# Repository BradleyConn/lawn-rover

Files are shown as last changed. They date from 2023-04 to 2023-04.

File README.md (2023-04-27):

# lawn-rover-program

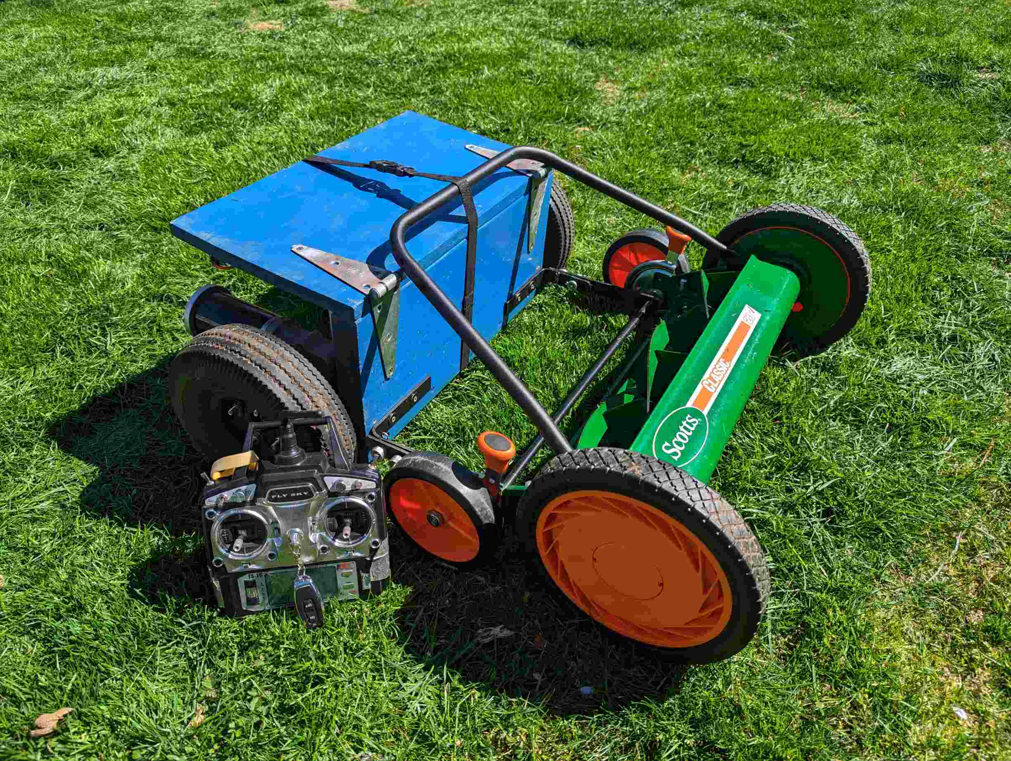
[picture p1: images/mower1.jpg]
Mower


Part of the lawn rover project. See [www.bradleyconn.space](https://www.bradleyconn.space/) for more details.
This is the main controller to interface with the remote reciever, interpret the signals, and interface to the motor drivers to drive the wheels.

An esp32 was used as I already had one readily available. Most microcontrollers would work. The Arduino IDE was used for its ease of use and effectiveness.

Everything was kept in a single file for simplicity, however that file has grown quite large and separate files should probably be considered.

## ESP32 wiring diagram
Below is how the ESP32 was connected to the R6B Receiver and connectors that attached to the wheel motor driver boards.

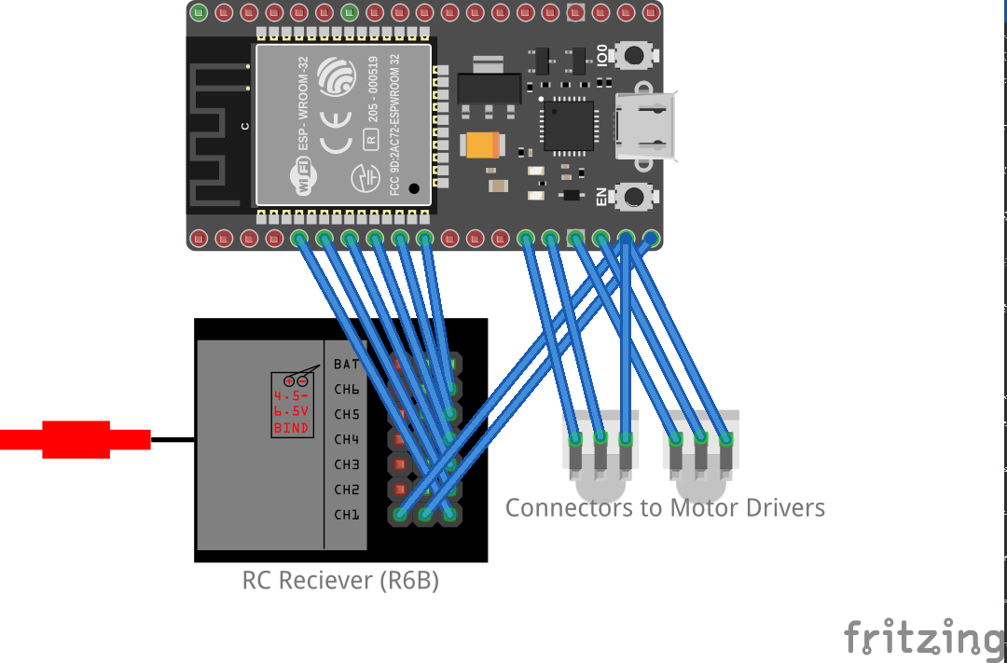
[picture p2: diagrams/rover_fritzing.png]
Wiring Diagram


## System block diagram

A block diagram of the entire system can be seen below. The microcontroller which this repo is concerned with is shown at the bottom.

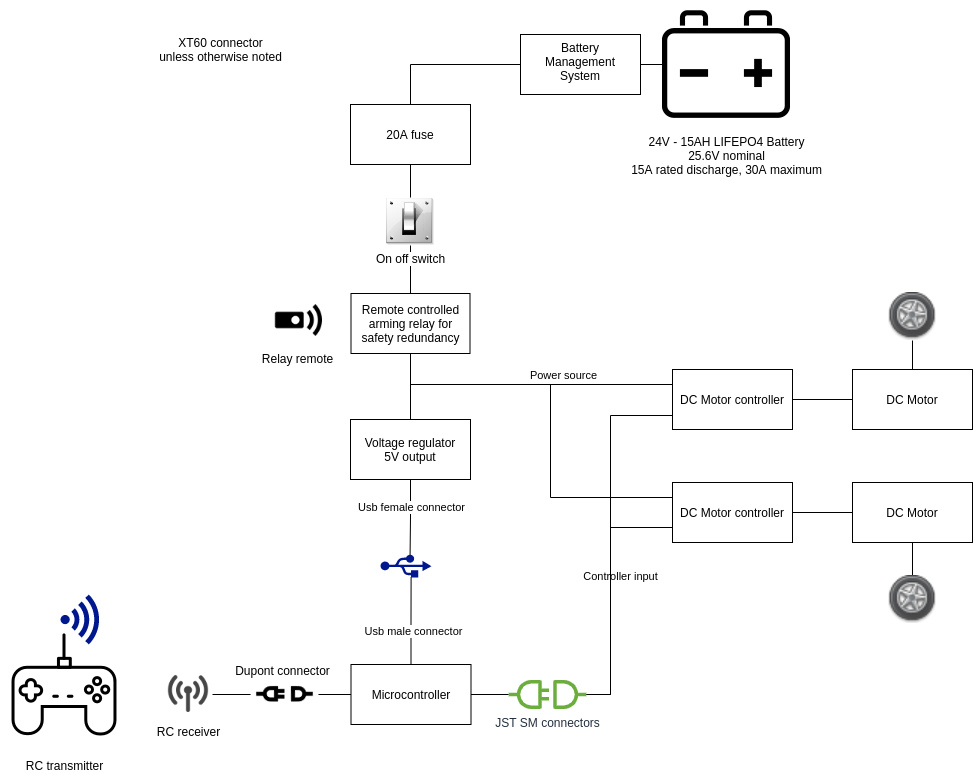
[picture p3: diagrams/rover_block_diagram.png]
System Block Diagram


And the actual wiring inside the system can be seen below.

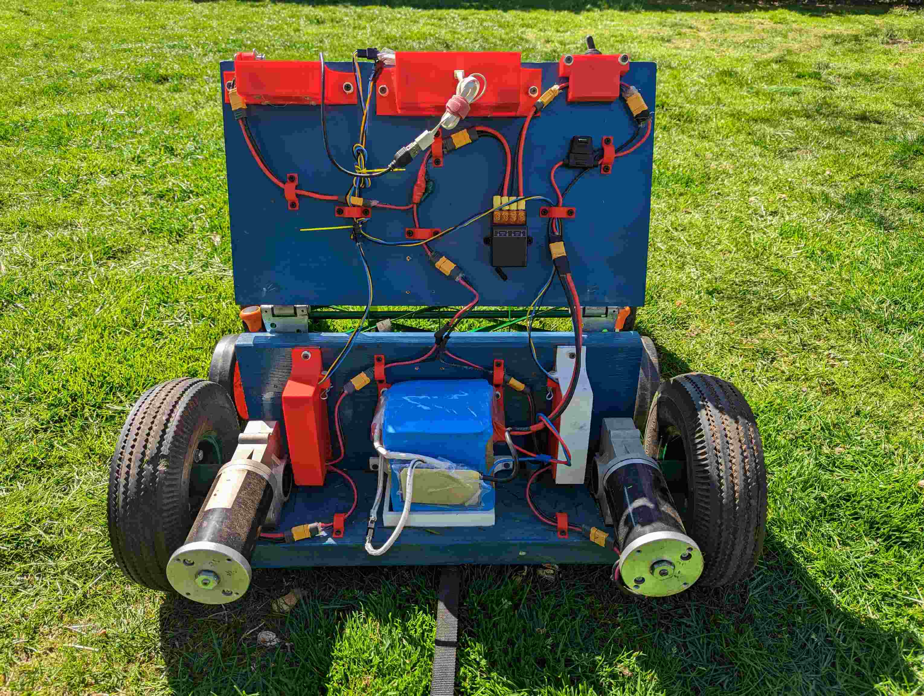
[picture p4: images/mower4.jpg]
Mower Inside


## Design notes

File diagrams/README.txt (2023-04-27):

rover_fritzing.png - A quick little wire diagram of how the esp32 connects to the RC reciever (R6B) and the two motor drivers.

rover_block_diagram.png - A block diagriam of the entire system. The microcontroller (and thus this repo) is labeled microcontroller. This is the brains behind the entire project, and you can see where it fits in with the overall project.

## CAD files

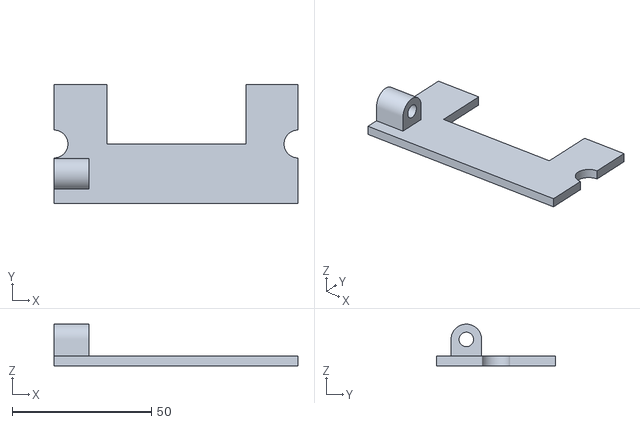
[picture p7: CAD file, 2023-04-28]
cad/stl/converter_lid_v1.stl
87.6 x 42.6 x 15.0

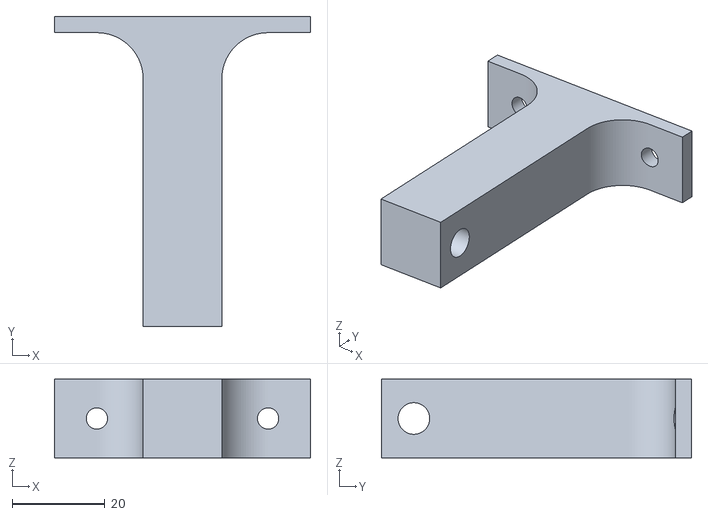
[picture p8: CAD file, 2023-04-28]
cad/stl/battery_arm.stl
55.4 x 67.0 x 17.0

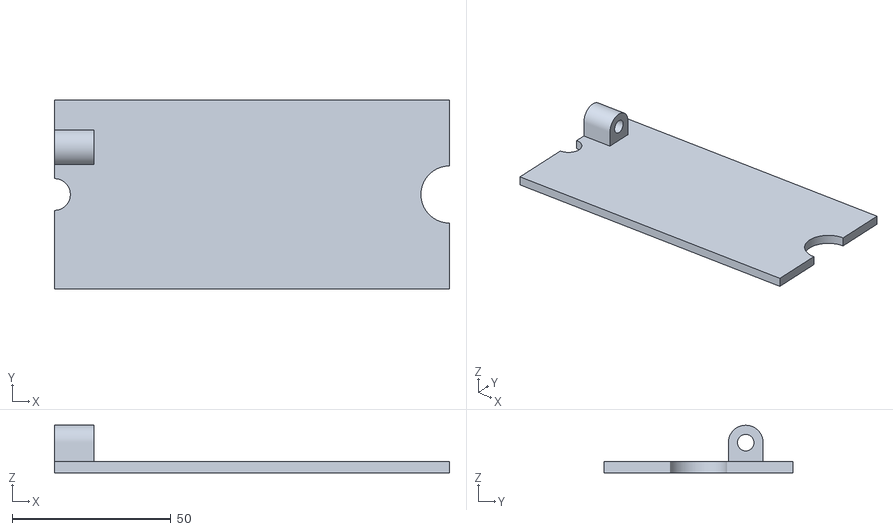
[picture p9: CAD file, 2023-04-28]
cad/stl/cytroncase_lid_v2_mirrored.stl
124.6 x 59.6 x 15.0

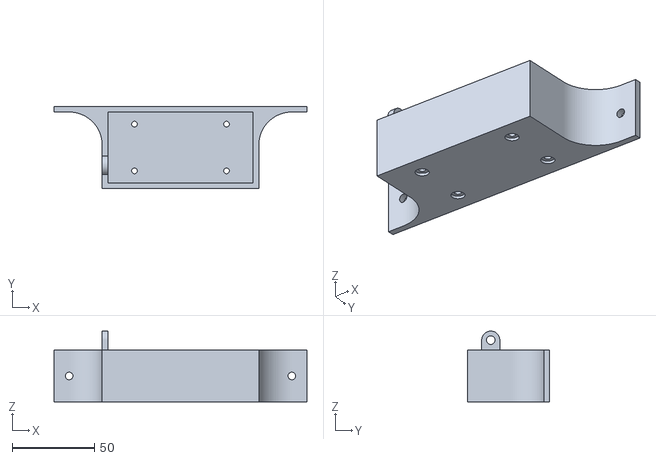
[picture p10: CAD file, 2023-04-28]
cad/stl/converter_v1.stl
153.4 x 50.0 x 43.0

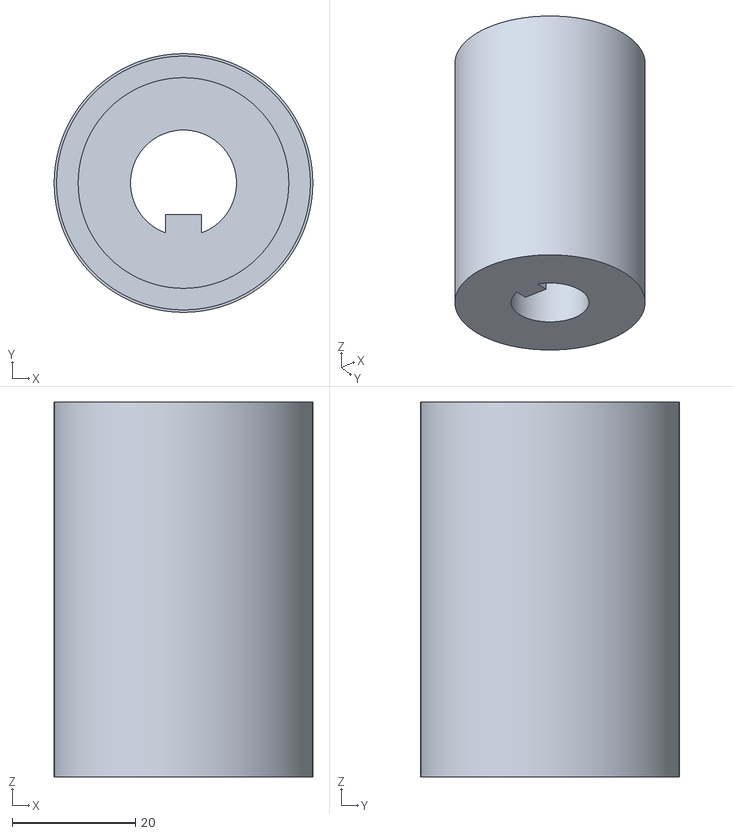
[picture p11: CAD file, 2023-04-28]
cad/stl/height_test.stl
42.0 x 42.0 x 60.9

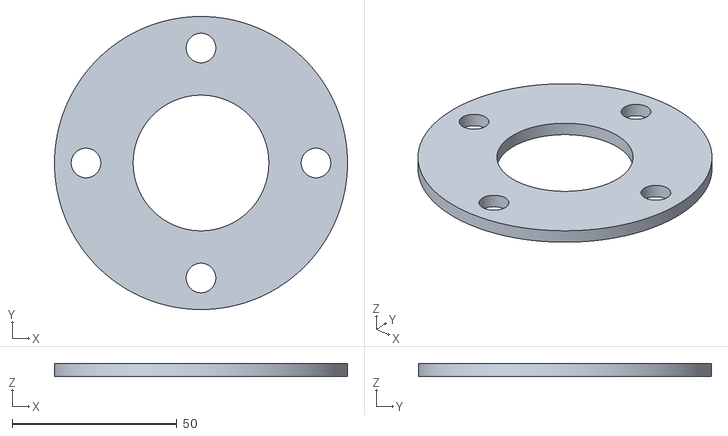
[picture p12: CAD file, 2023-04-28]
cad/stl/pipe_mount.stl
89.0 x 89.0 x 4.00

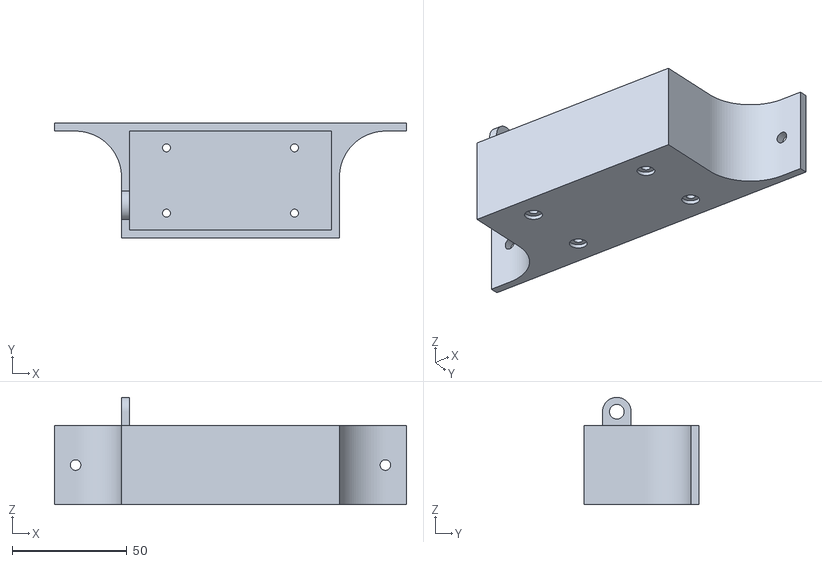
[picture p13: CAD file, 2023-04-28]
cad/stl/regulator_v2.stl
153.4 x 50.0 x 46.8

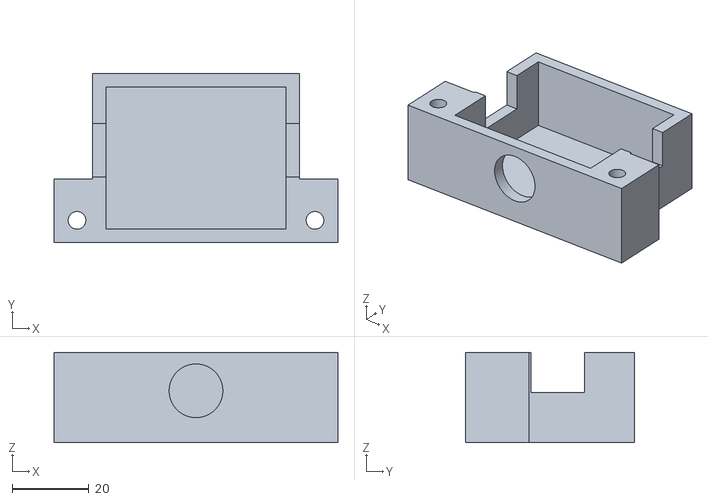
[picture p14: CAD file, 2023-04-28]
cad/stl/toggle_switch_v2.stl
74.0 x 44.0 x 23.5

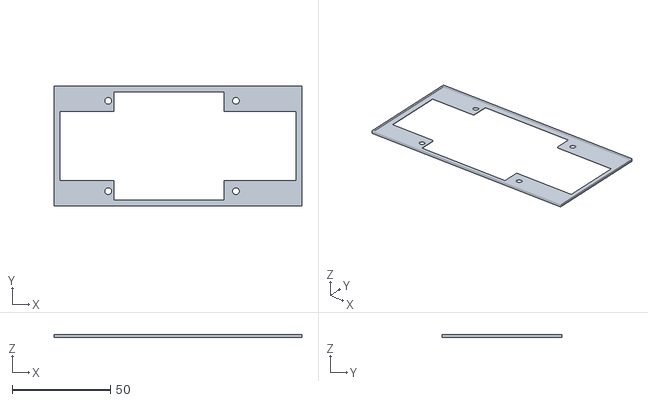
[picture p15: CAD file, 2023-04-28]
cad/stl/esp32-test.stl
126.2 x 61.2 x 1.60

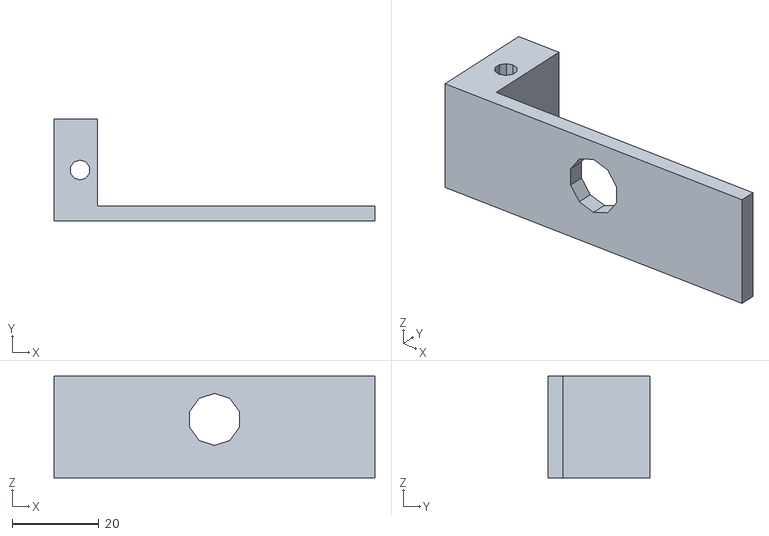
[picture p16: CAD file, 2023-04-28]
cad/stl/toggle_switch.stl
74.0 x 23.5 x 23.5

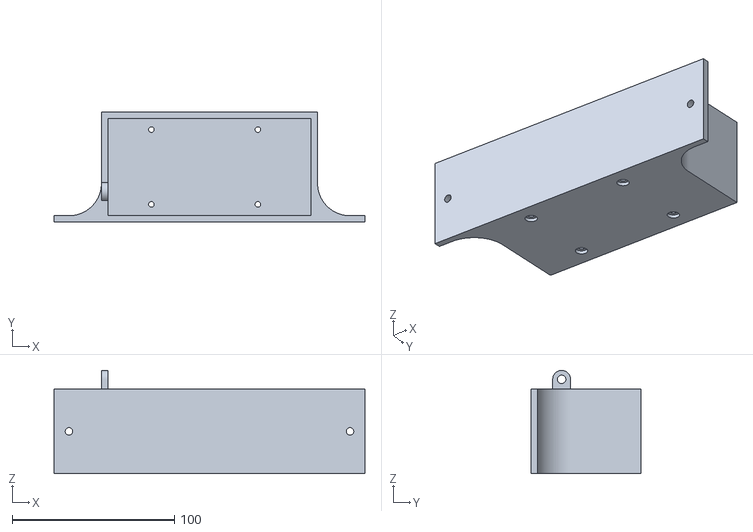
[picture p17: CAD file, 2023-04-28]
cad/stl/esp32.stl
191.4 x 68.0 x 63.5

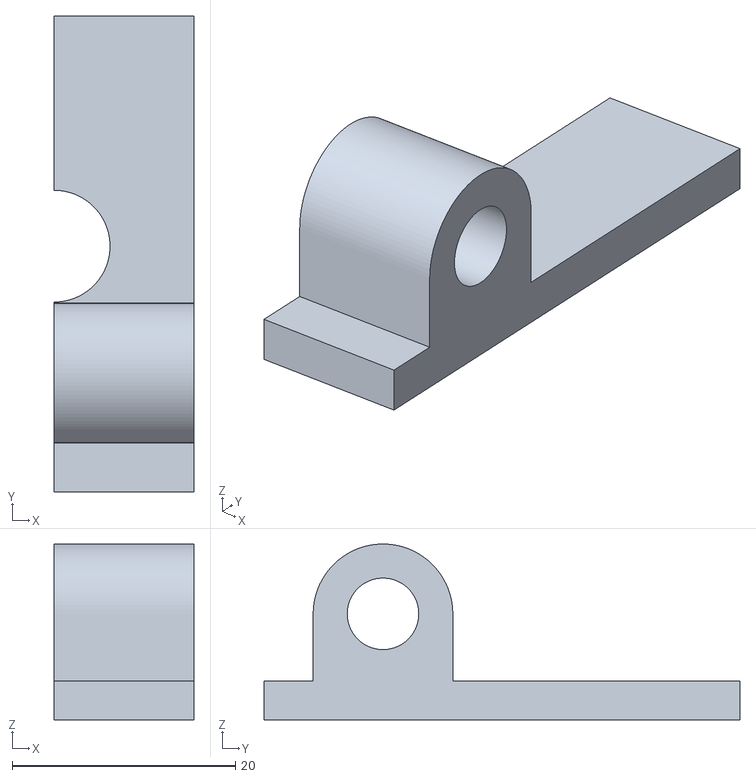
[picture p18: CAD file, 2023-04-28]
cad/stl/regulator_lid_v2.stl
12.5 x 42.6 x 15.8

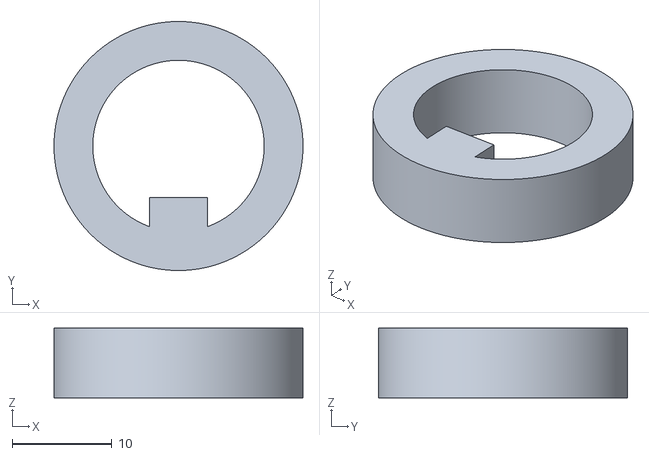
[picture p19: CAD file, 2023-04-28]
cad/stl/keyed_coupler.stl
25.0 x 25.0 x 7.00

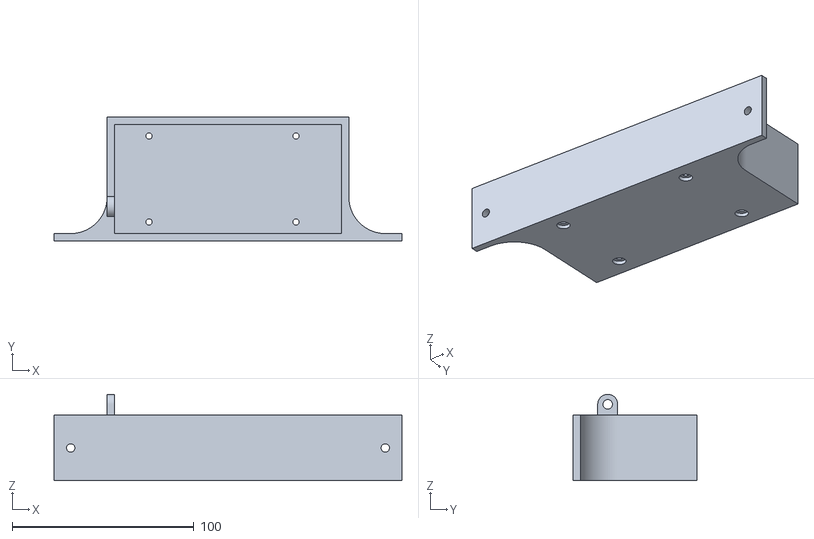
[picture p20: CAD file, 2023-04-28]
cad/stl/cytroncase_v2.stl
191.4 x 68.0 x 47.5

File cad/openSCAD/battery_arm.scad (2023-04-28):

length = 60;//52;
width = 10;//86;
height = 10;
wall = 3.5;
o_width = width + wall + wall;
o_length = length + wall + wall;
o_height = height + wall + wall;

resolution = 100;

$fn = resolution;

// outer box
standoff_id=3.45;
standoff_od=7;
standoff_od_wall_depth = wall-2;
standoff_width = 55.8;
standoff_length = 28.4;
// main box
//add the pin mechanism
pin_od = 11;
pin_id = 5.2*(4/3)-.1;
wall_offset = 6;
difference() {
    cube([o_width, o_length, o_height]);
    rotate([0,90,0]) {
        translate([-(height+wall+wall)/2,wall+wall,0]) {
            cylinder(h=9000, d=pin_id);   
        }
    }
}
//}


mount_arm_surface_area = 10;
screwhole_size = 4.6;
//box_mount_hole_1
translate([0,o_length,0]) {
mirror([0,1,0]) {
rotate(90){
    difference() {
        union() {
            difference() {
                cube([mount_arm_surface_area+wall, mount_arm_surface_area, o_height]);
                // angled for strength
                translate([mount_arm_surface_area+wall, mount_arm_surface_area, -1]){
                    cylinder(h=9999, r=mount_arm_surface_area);
                }
            }
            cube([wall, mount_arm_surface_area+screwhole_size*2, o_height]);
        }
        // screw hole
        rotate([0,90,0]) {
            translate([-o_height/2, mount_arm_surface_area, -1]){
                cylinder(h=9999, d=screwhole_size);
            }
        }
    }
}
//box mount hole 2
//copied and pasted but translated an mirrored
translate([o_width, 0, 0]){
    mirror([1,0,0]){
        rotate(90) {
            difference() {
                union() {
                    difference() {
                        cube([mount_arm_surface_area+wall, mount_arm_surface_area, o_height]);
                        // angled for strength
                        translate([mount_arm_surface_area+wall, mount_arm_surface_area, -1]){
                            cylinder(h=9999, r=mount_arm_surface_area);
                        }
                    }
                    cube([wall, mount_arm_surface_area+screwhole_size*2, o_height]);
                }
                // screw hole
                rotate([0,90,0]) {
                    translate([-o_height/2, mount_arm_surface_area, -1]){
                        cylinder(h=9999, d=screwhole_size);
                    }
                }
            }
        }
    }
}
}
}

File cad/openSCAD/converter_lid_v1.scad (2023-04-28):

length = 43-.4;//52;
width = 88-.4;//86;
height = 32;
wall = 3.5;
o_width = width + wall + wall;
o_length = length + wall + wall;
o_height = height + wall;

resolution = 100;

$fn = resolution;

// outer box
standoff_id=3.45;
standoff_od=7;
standoff_od_wall_depth = wall-2;
standoff_width = 80.8;
standoff_length = 47.25;
//difference(){
    // main box
    //cube([o_width, o_length, o_height]);
    translate([wall, wall, 0]) {
        translate([0, 0, wall]) {
            // 9999 to take out the whole face
            difference(){
            cube([width, length, wall]);
                translate([width, length/2, 0]) {
                    cylinder(h=100, r=5);
                }
                translate([0, length/2, 0]) {
                    cylinder(h=100, r=5);
                }
                        translate([19, length/2, 0]) {

            cube([50, length/2, wall]);
                        }

            }
        }
    }
//}


//add the pin mechanism
pin_od = 11;
pin_id = 5.2;
pin_len = 16;
wall_offset = 6;
translate([wall, (1/4)*length+wall-pin_od/2, wall+wall]){
    difference() {
        union(){
            cube([pin_len-wall, pin_od, wall_offset]);
            rotate([0,90,0]) {
                translate([-wall_offset,pin_od/2,0]) {
                    cylinder(h=pin_len-wall, d=pin_od);
                }
            }
        }
        rotate([0,90,0]) {
            translate([-wall_offset,pin_od/2,0]) {
                cylinder(h=pin_len-wall, d=pin_id);   
            }
        }
    }
}

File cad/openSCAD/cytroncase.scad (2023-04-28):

/**
 * pin_length is measured along the same axis as the length of the board.
 * pin_width is the width of the bottom of the pins, where they're widest.
 * pin_thickness is measured along the same axis as the board thickness.
 * tail_width is the width of the tails where they meet the bottom of the pins, where they're narrowest.
 */
module dovetail_pins(pin_length=.75, pin_width=1, pin_thickness=.75, pin_count=4, angle=15, tail_width=1) {
    intersection() {
        translate([0.005, 0.005, 0.005]) cube([(pin_count-1)*(pin_width+tail_width)-0.01, pin_length-0.01, pin_thickness-0.01]);
        dovetail_pins_idealized(
            pin_length=pin_length,
            pin_width=pin_width,
            pin_thickness=pin_thickness,
            pin_count=pin_count,
            angle=angle,
            tail_width=tail_width
        );
    }
}

/**
 * tail_length is measured along the same axis as the length of the board.
 * tail_width is the width of the tails where they meet the board, where they're narrowest.
 * tail_thickness is measured along the same axis as the board thickness.
 * pin_width is the width of the bottom of the pins, where they're widest.
 */
module dovetail_tails(tail_length=.75, tail_width=1, tail_thickness=.75, tail_count=3, angle=15, pin_width=1) {
    pin_count = tail_count + 1;
    pin_thickness = tail_length;
    pin_length = tail_thickness;
    
    translate([0, 0, tail_thickness]) {
        rotate([-90, 0, 0]) {
            translate([0, 0, -0.005]) {
                difference() {
                    translate([0.005, 0.005, 0.005]) {
                        cube([(pin_count-1)*(pin_width+tail_width)-0.01, tail_thickness-0.01, tail_length-0.01]);
                    }

                    dovetail_pins_idealized(
                        pin_length=pin_length,
                        pin_width=pin_width,
                        pin_thickness=pin_thickness,
                        pin_count=pin_count,
                        angle=angle,
                        tail_width=tail_width
                    );
                }
            }
        }
    }
}

/**
 * Used for generating both pins and tails. Don't call this directly.
 */
module dovetail_pins_idealized(
    pin_length=.75,
    pin_width=1,
    pin_thickness=.75,
    pin_count=4,
    angle=15,
    tail_width=1) {
        
    pin_width_top = pin_width - ( 2 * tan(angle) * pin_thickness );
    
    translate([0, pin_length, 0]) {
        rotate([90, 0, 0]) {
            intersection() {
                cube([(pin_count-1)*(pin_width+tail_width), pin_thickness, pin_length]);
                
                for (pin = [0:pin_count-1]) {
                    translate([pin * (pin_width + tail_width), 0]) {
                        linear_extrude(pin_length) {
                            polygon([
                                [-pin_width/2, 0], 
                                [-pin_width_top/2, pin_thickness],
                                [pin_width_top/2, pin_thickness],
                                [pin_width/2, 0]
                            ]);
                        }
                    }
                }
            }
        }
    }
}

/**
 * Determine the width the pins need to be once the tail widths are chosen.
 */
function pin_width (tail_width, tail_count, board_width) = ( board_width - (tail_width * tail_count) ) / (tail_count);

/**
 * Construct a board with tails cut into it. board_length includes the length of the tails.
 */
module board_with_dovetail_tails(board_length, board_width, board_thickness, tail_length, tail_width, pin_width, tail_count, angle) {
    
    tail_thickness = board_thickness;
    
    pin_width = pin_width(tail_width = tail_width, tail_count=tail_count, board_width=board_width);
    translate([0, board_length - ( 2 * tail_length) + tail_length, 0]) {
        dovetail_tails(tail_length=tail_length, tail_width=tail_width, tail_thickness=tail_thickness, tail_count=tail_count, angle=angle, pin_width=pin_width);
    }
    translate([0, tail_length, 0]) cube([board_width, board_length - ( 2 * tail_length), board_thickness]);
    translate([0, tail_length, 0]) mirror([0,1,0]) dovetail_tails(tail_length=tail_length, tail_width=tail_width, tail_thickness=tail_thickness, tail_count=tail_count, angle=angle, pin_width=pin_width);
}

/**
 * Construct a board with pins cut into it. board_length includes the length of the pins.
 */
module board_with_dovetail_pins(board_length, board_width, board_thickness, pin_length, tail_width, pin_width, pin_count, angle) {
    translate([0, board_length - ( 2 * pin_length) + pin_length, 0]) {
        dovetail_pins(pin_length=pin_length, pin_width=pin_width, pin_thickness=board_thickness, pin_count=pin_count, angle=angle, tail_width=tail_width);
    }
    translate([0, pin_length, 0]) cube([board_width, board_length - ( 2 * pin_length), board_thickness]);
        dovetail_pins(pin_length=pin_length, pin_width=pin_width, pin_thickness=board_thickness, pin_count=pin_count, angle=angle, tail_width=tail_width);
}

length = 52;
width = 86;
bottom_height = 10;
wall = 4;
o_width = width + wall;
o_length = length + wall;

resolution = 1000;

$fn = resolution;

//cube([o_width, o_length, bottom_height]);

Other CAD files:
cad/stl/cytroncase_v2_mirrored.stl
cad/stl/esp32_lid_v1.stl
cad/stl/cytroncase_lid_v2.stl
cad/stl/mount_insert.stl
cad/openSCAD/converter_v1.scad
cad/openSCAD/cytroncase_lid_v2.scad
cad/openSCAD/cytroncase_lid_v2_mirrored.scad
cad/openSCAD/cytroncase_v2.scad
cad/openSCAD/cytroncase_v2_mirrored.scad
cad/openSCAD/esp32.scad
cad/openSCAD/esp32_lid_v1.scad
cad/openSCAD/keyed_coupler.scad
cad/openSCAD/keyed_coupler_mount.scad
cad/openSCAD/mount_full.scad
cad/openSCAD/mount_insert.scad
cad/openSCAD/pipe_mount.scad
cad/openSCAD/regulator_lid_v2.scad
cad/openSCAD/regulator_v2.scad
cad/openSCAD/toggle_switch.scad

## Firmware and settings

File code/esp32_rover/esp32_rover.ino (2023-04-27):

/***  www.bradleyconn.space ***/

/**
 * This is the "production" code.
 * It strips out the "leds as motors" testing.
 * It leaves all the printing because it isn't that time sensitive with smoothing turned on.
 * This file is way longer than it should be but it's kept that
 * way to be really easy to import into the Arduino IDE and use.
 * 
 */

#include <Arduino.h>
// ESP32 needs a special analog write library
#include <analogWrite.h>

// pin definitions
const uint8_t pin_ch1 = 34;
const uint8_t pin_ch2 = 35;
const uint8_t pin_ch3 = 32;
const uint8_t pin_ch4 = 33;
const uint8_t pin_ch5 = 25;
const uint8_t pin_ch6 = 26;

const uint8_t pin_reverse_left = 12; // pin not good as an input
const uint8_t pin_reverse_right = 14;

const uint8_t pin_left = 13;
const uint8_t pin_right = 27;

/****************************************
  This is how the controller mapping goes
     right stick x    = ch1
     right stick y    = ch2
     left stick y     = ch3
     left stick x     = ch4
     top right switch = ch5
     top left wtich   = ch6
****************************************/

// TODO: Make a calibration routine with a button
// May only need to do it for one channel and apply to all
const int ch1_max = 2000;
const int ch1_min = 1000;
const int ch2_max = 1822;
const int ch2_min = 922;
const int ch3_max = 2000;
const int ch3_min = 1000;
const int ch4_max = 2000;
const int ch4_min = 1000;

/**
 * Some smoothing params for the function below!
 * Globals are used for easy resetting
 */
// Step per second allowed.
// As a guess, don't go more than 50% in half a second? that might be slow...
// Range is from -500 to +500
#define max_step  75
#define step_time_ms  50
// Variables to store the historical data
int prev_left = 0;
int prev_right = 0;
// This needs to be updated on every call to smooth that updates AND every reset smooth
unsigned long prev_time = 0;
// A function that can be used to reset the values
void reset_smoothing_function() {
  prev_left = 0;
  prev_right = 0;
  prev_time = millis();
}

/**
 * This functions take a left wheel and right wheel signal and use historical data
 * to smooth the control experiance. The parameters are inout params
 * Motivation:
 * Quick changes in the motors is violent on the vehicle and its electronics.
 * Try to reduce instantanious large changes.
 * Keep some historical data to make informed corrections.
 * 
 * @param *left - in out param for the drive signal the motor
 * @param *right - in out param for the drive signal of the motor
 */
void smooth_driving(int * left, int * right) {
  Serial.print("Millis: ");
  Serial.println(millis());
  // This can all be done way better but for now take a simplistic approach and feel it out
  // Simple approach - find a good balance of maximum step function in one step, and frequency of steps.
  // TODO: Better approach - always update but limit the step to a step per ms ratio, with an additional maximum step constraint
  
  // If it's been to soon don't update
  if(millis() - prev_time < step_time_ms){
    // Too quick to update so use the previous values
    *left = prev_left;
    *right = prev_right;
    return;
  }

  // Over step time so do an update
  int target_left = *left;
  int target_right = *right;
  int left_smoothed = 0;
  int right_smoothed = 0;

  // Left side
  // If adding forward power
  if(target_left > prev_left) {
    int step_difference = target_left - prev_left;
    if(step_difference > max_step) {
      step_difference = max_step;
    }
    left_smoothed = prev_left + step_difference;
  }
  // Adding backwards power
  else {
    int step_difference = prev_left - target_left;
    if(step_difference > max_step) {
      step_difference = max_step;
    }
    left_smoothed = prev_left - step_difference;
  }

  // Right side
  // If adding forward power
  if(target_right > prev_right) {
    int step_difference = target_right - prev_right;
    if(step_difference > max_step) {
      step_difference = max_step;
    }
    right_smoothed = prev_right + step_difference;
  }
  // Adding backwards power
  else {
    int step_difference = prev_right - target_right;
    if(step_difference > max_step) {
      step_difference = max_step;
    }
    right_smoothed = prev_right - step_difference;
  }
  
  *left = left_smoothed;
  *right = right_smoothed;

  //update the values
  prev_left = *left;
  prev_right = *right;
  prev_time = millis();
}

/**
 * This is the function that takes the left and right drive strength and direction
 * and sends it out to the motor.
 * 
 * Left and right are ints where negative indicates going in the reverse direction
 * The values should be between -500 and 500
 * The motor driver splits it into a direction signal (binary) and a strength signal (variable)
 * 
 * @param int left - left drive value between -500 and 500
 * @param int right - right drive value between -500 and 500
 */
void drive(int left, int right) {
  // The rover can have pretty harsh instantaneous behavior
  // so apply and algorithm to smooth out the harshness
  // These are inout params
  smooth_driving(&left, &right);

  Serial.println(left);
  Serial.println(right);

  // Deduce the direction of each motor and send the signal
  // Also ensure the speed is a positive number 
  if (left < 0) {
    // reverse on
    digitalWrite(pin_reverse_left, HIGH);
    left = abs(left); 
    Serial.println("left reverse");
  }
  else {
    //reverse off
    digitalWrite(pin_reverse_left, LOW);
    Serial.println("left forward");
  }

  if (right < 0) {
    //reverse on
    digitalWrite(pin_reverse_right, HIGH);
    right = abs(right);
    Serial.println("right reverse");
  }
  else {
    //reverse off
    digitalWrite(pin_reverse_right, LOW);
    Serial.println("right forward");
  }

 //clip the values over 500, and set anything over 450 to max
  if (left > 450) {
    left = 500; 
  }
  if (right > 450) {
    right = 500;
  }
 //clip the values under 100 to keep sensitivity down
  if (left < 100) {
    left = 0; 
  }
  if (right < 100) {
    right = 0;
  }

  uint32_t left_mapped = (uint32_t)map(left, 0, 500, 0, 255);
  uint32_t right_mapped = (uint32_t)map(right, 0, 500, 0, 255);
  //The left wheel is about 9/10th the speed of the right wheel.
  //Limit the right wheel by that much
  uint32_t  right_mapped_calibrated = (right_mapped * 9) / 10;
  analogWrite(pin_left, left_mapped);
  analogWrite(pin_right, right_mapped_calibrated);

  Serial.print("left power");
  Serial.println(map(left, 0, 500, 0, 255));
  Serial.print("right power ");
  Serial.println(map(right, 0, 500, 0, 255));
}

/**
 * This function takes left-right, up-down controller axis, maps it to a left
 * and right wheel. Then sends it to the motor for actuation.
 * 
 * @param ch_x_mapped - the left-right value. Left is negative.
 * @param ch_y_mapped - the up-down value. Down is negative.
 */
void single_stick_drive(int ch_x_mapped, int ch_y_mapped) {
  // Cool little "algorithm". Easy enough to think through.
  int left = ch_y_mapped + ch_x_mapped;
  int right = ch_y_mapped - ch_x_mapped;

  // if we're definitely going backwards switch which wheel to reverse on.
  if(ch_y_mapped<-100) {
    left = ch_y_mapped - ch_x_mapped;
    right = ch_y_mapped + ch_x_mapped;
  }
  if (left > 500) {
    left = 500;
  }
  else if (left < -500) {
    left = -500;
  }
  if (right > 500) {
    right = 500;
  }
  else if (right < -500) {
    right = -500;
  }
  drive(left, right);
}


/**
 * This function takes left-right, up-down controller axis, maps it to a left
 * and right wheel. Then sends it to the motor for actuation.
 * 
 * @param left - the left stick value. Down is negative.
 * @param right - the Right stick value. Down is negative.
 */
void dual_stick_drive(int left, int right) {
  drive(left, right);
}

void setup() {
  // initialize digital pin LED_BUILTIN as an output.
  pinMode(LED_BUILTIN, OUTPUT);

  pinMode(pin_ch1, INPUT); // Set our input pins as such
  pinMode(pin_ch2, INPUT);
  pinMode(pin_ch3, INPUT);
  pinMode(pin_ch4, INPUT);
  pinMode(pin_ch5, INPUT);
  pinMode(pin_ch6, INPUT);
  
  //control pins
  pinMode(pin_reverse_left, OUTPUT);
  pinMode(pin_reverse_right, OUTPUT);
  pinMode(pin_left, OUTPUT);
  pinMode(pin_right, OUTPUT);

  Serial.begin(115200);

  //disable all motor output on start up.
  digitalWrite(pin_right, LOW);
  digitalWrite(pin_left, LOW);
  digitalWrite(pin_reverse_right, LOW);
  digitalWrite(pin_reverse_left, LOW);
}

void loop() {
  // Read the pulse width of each channel
  int ch1 = pulseIn(pin_ch1, HIGH, 25000); // Read the pulse width of 
  int ch2 = pulseIn(pin_ch2, HIGH, 25000); // each channel
  int ch3 = pulseIn(pin_ch3, HIGH, 25000);
  int ch4 = pulseIn(pin_ch4, HIGH, 25000);
  int ch5 = pulseIn(pin_ch5, HIGH, 25000);
  int ch6 = pulseIn(pin_ch6, HIGH, 25000);

  int ch1_mapped = map(ch1, ch1_min,ch1_max,-500,500);
  int ch2_mapped = map(ch2, ch1_min,ch1_max,-500,500);
  int ch3_mapped = map(ch3, ch1_min,ch1_max,-500,500);
  int ch4_mapped = map(ch4, ch1_min,ch1_max,-500,500);
  int ch5_mapped = map(ch5, ch1_min,ch1_max,-500,500);
  int ch6_mapped = map(ch6, ch1_min,ch1_max,-500,500);

  int right_stick_up_down = ch2_mapped;
  int right_stick_left_right = ch1_mapped;
  int left_stick_up_down = ch3_mapped;
  int left_stick_left_right = ch4_mapped;
  int left_toggle = ch6_mapped;
  int right_toggle = ch5_mapped;

  Serial.print("Right stick updown: "); // center at 0
  Serial.println(right_stick_up_down);
  Serial.print("Right stick leftright: ");
  Serial.println(right_stick_left_right);
  Serial.print("Left stick updown: ");
  Serial.println(left_stick_up_down);
  Serial.print("Left stick leftright: ");
  Serial.println(left_stick_left_right);
  Serial.println("");

  bool single_stick = false;
  bool dual_stick = false;
  if(left_toggle>0){
    Serial.println("Left Switch: Engaged");
    dual_stick = true;
    //single_stick = false;
  } 
  else {
    Serial.println("Left Switch: Disengaged");
    single_stick = true;
    //dual_stick = false;
  }

  bool controls_forwards = false;
  bool controls_backwards = false;
  if(right_toggle>0){
    Serial.println("Right Switch: Engaged");
    controls_forwards = true;
    //controls_backwards = false;
  } 
  else {
    Serial.println("Right Switch: Disengaged");
    controls_backwards = true;
    //controls_forwards = false;
  }

  // Check to see if the controller is connected by seeing if the values read are within the range.
  // Check the 4 important channels to make sure there's no loose wires which could cause the vehicle to move unintentionally
  // Use a decent buffer to reduce potential misinterpretations
  int buff = 300;
  // If the controller isn't connected
  if(  ch1 < (ch1_min - buff) || ch1 > (ch1_max + buff)
    || ch2 < (ch2_min - buff) || ch2 > (ch2_max + buff)
    || ch3 < (ch3_min - buff) || ch3 > (ch3_max + buff)
    || ch4 < (ch4_min - buff) || ch4 > (ch4_max + buff)) {
    digitalWrite(LED_BUILTIN, HIGH);   // turn the LED on (HIGH is the voltage level)

    //disable everything
    digitalWrite(pin_right, LOW);
    digitalWrite(pin_left, LOW);
    digitalWrite(pin_reverse_right, LOW);
    digitalWrite(pin_reverse_left, LOW);

    // Controller isn't connected so reset the drive state for when it comes back online.
    reset_smoothing_function();
  }
  // Controller is connected let's do this!
  else {
    //enable on
    digitalWrite(LED_BUILTIN, LOW);  
    if (single_stick) {
      if(!controls_backwards) {
        single_stick_drive(right_stick_left_right, right_stick_up_down);
      }
      else {
        //negate the values which will flip them
        right_stick_left_right = -right_stick_left_right;
        right_stick_up_down = -right_stick_up_down;
        single_stick_drive(right_stick_left_right, right_stick_up_down);
      }
    }
    else if (dual_stick) {
      if(!controls_backwards) {
        dual_stick_drive(left_stick_up_down, right_stick_up_down);
      }
      else {
        //swap left and right and forward and back
        int new_right_stick_up_down = -left_stick_up_down;
        int new_left_stick_up_down = -right_stick_up_down;
        dual_stick_drive(new_left_stick_up_down, new_right_stick_up_down);
      }
    }
  }
}
